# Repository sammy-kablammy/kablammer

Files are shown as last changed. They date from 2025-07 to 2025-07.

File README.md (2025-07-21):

# the kablammer

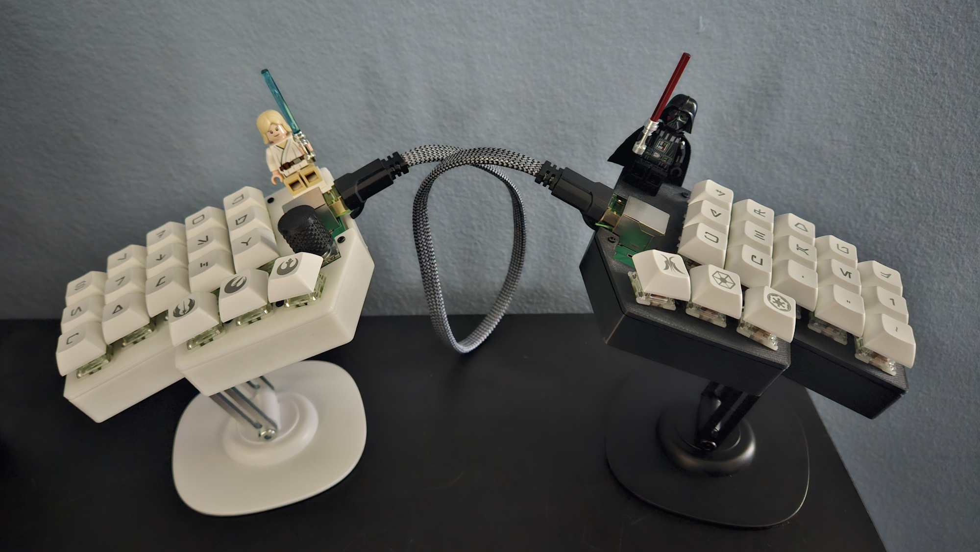
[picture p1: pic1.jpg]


A 36-key split ergo keeb to optimize your efficiency in dynamic heuristic analysis, improving synergy and interpolation of functional pseudo-discrete technical shizzle wizzles. Guaranteed to make you a 1000x front/back/middle end full stack vibe coded prompt engineer or your money back.

Features:
- [x] Reversible PCB
- [x] RP2040 zero microcontrollers (cheap + uses USB C)
- [x] Rotary encoder for volume or scrollwheel
- [x] RJ45 connects the two halves
- [x] Can seat two minifigures for moral support during intense debugging sessions

Case is made in FreeCAD. I just use the same model for both halves, but mirrored. The halves are not exactly the same, so you'll get slightly larger slots than necessary. I use a magsafe sticker on the bottom of each half. Then you can use magsafe phone stands for tenting.

Firmware is in [my QMK fork](https://github.com/sammy-kablammy/qmk_firmware.git).

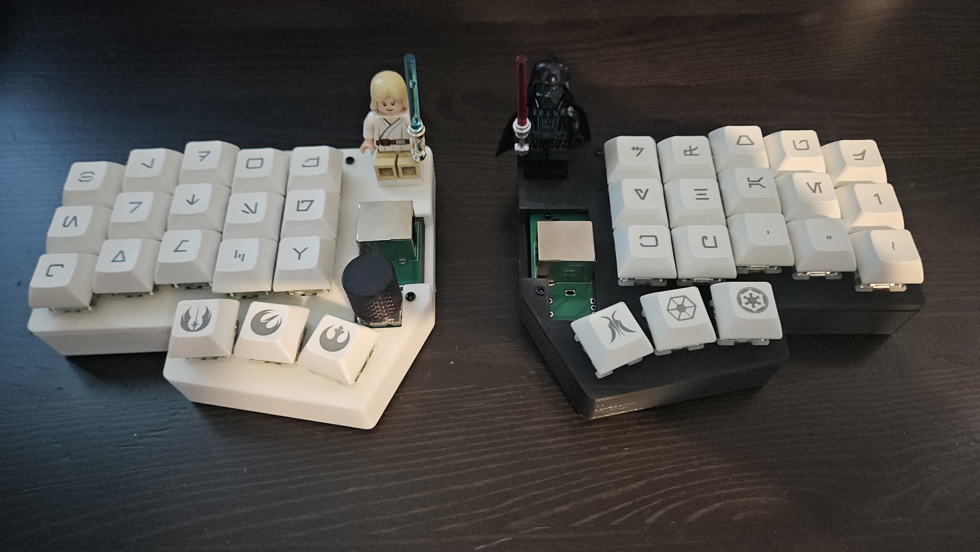
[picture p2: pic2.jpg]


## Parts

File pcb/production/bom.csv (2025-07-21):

Designator | Footprint | Quantity | Value | LCSC Part #
D1, D10, D11, D12, D13, D14, D15, D16, D17, D18, D19, D2, D3, D4, D5, D6, D7, D8, D9 | Diode_DO-35 | 19 | Diode
J1 | RJ45_Ninigi_GE | 1 | RJ45_Shielded_left
J2 | RJ45_Ninigi_GE | 1 | RJ45_Shielded_right
S1, S10, S11, S12, S13, S14, S15, S16, S17, S18, S2, S3, S4, S5, S6, S7, S8, S9 | Hotswap_MX_1.00u_reversible | 18 | Keyswitch
SW1 | Encoder_EC11_MX | 1 | RotaryEncoder_Switch
U2 | RP2040_Zero | 1 | RP2040_Zero

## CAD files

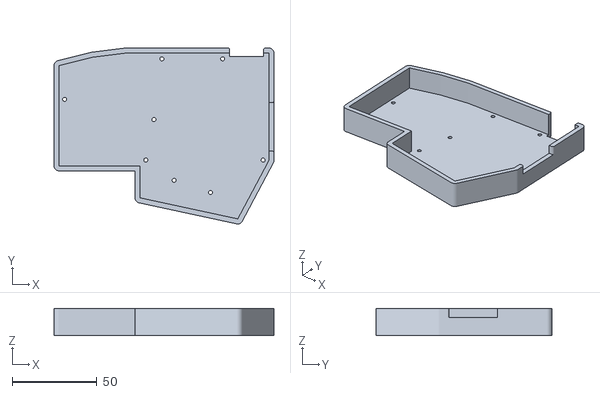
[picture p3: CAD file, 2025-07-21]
case/kablammer_case-LeftBottom.stl
129.4 x 103.5 x 16.0

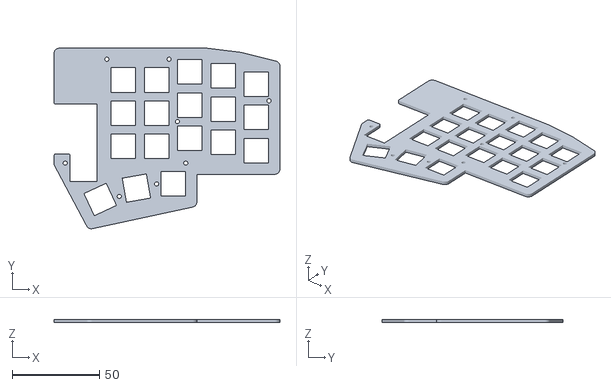
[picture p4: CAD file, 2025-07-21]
case/kablammer_case-RightTop.stl
129.5 x 103.5 x 2.00

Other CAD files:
case/kablammer_case-RightBottom.stl
case/kablammer_case-LeftTop.stl

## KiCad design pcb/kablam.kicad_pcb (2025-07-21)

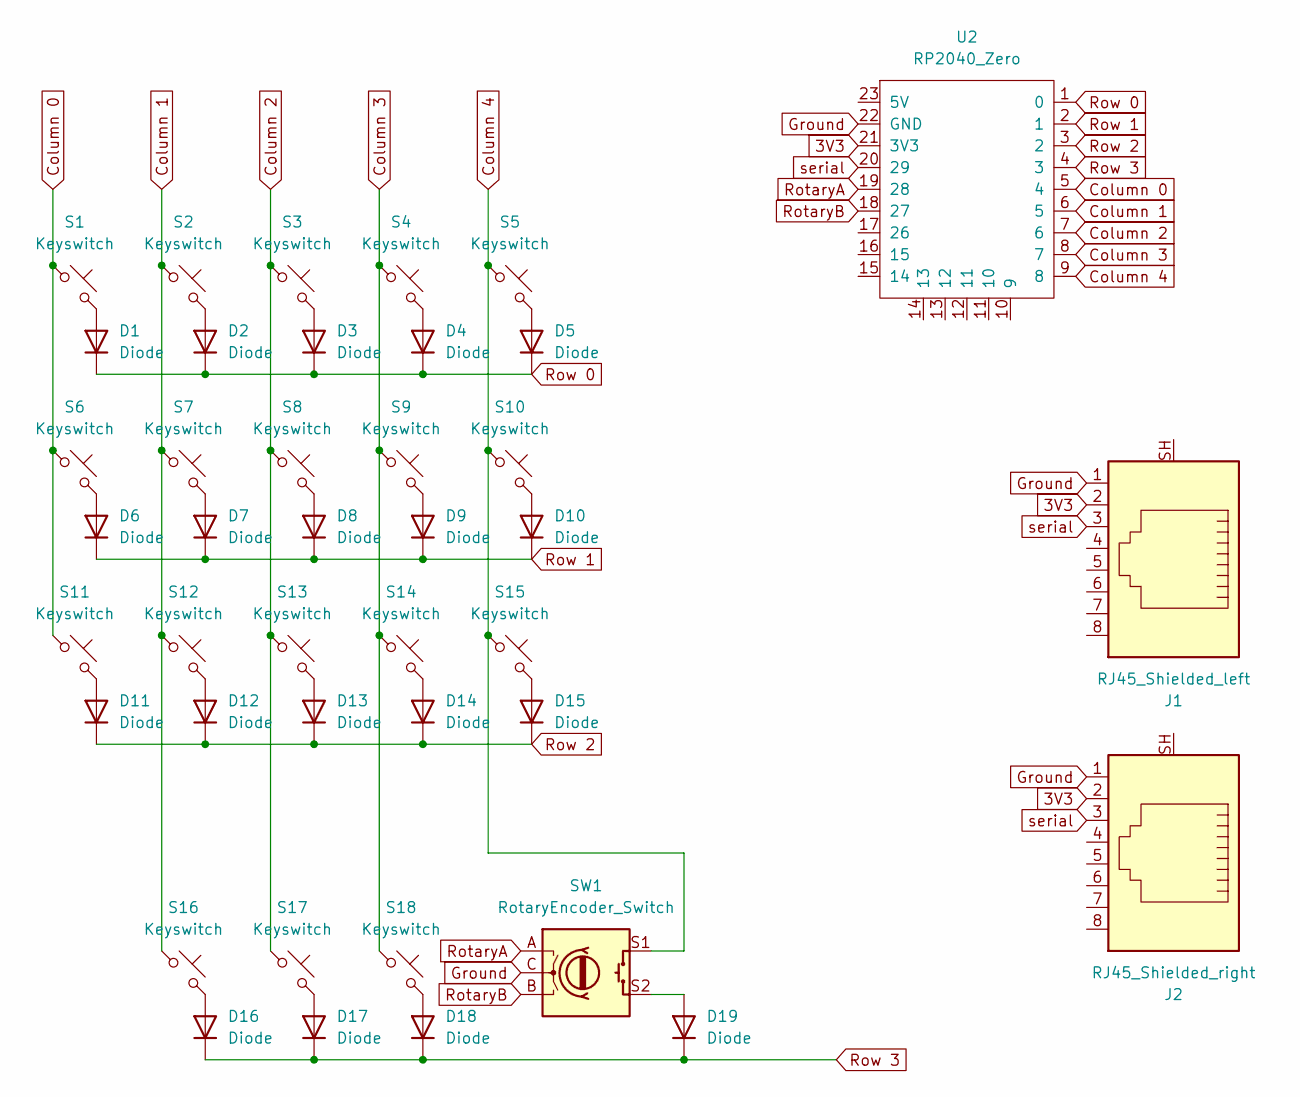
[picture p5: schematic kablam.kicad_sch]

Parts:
D1, D2, D3, D4, D5, D6, D7, D8, D9, D10, D11, D12, D13, D14, D15, D16, D17, D18, D19: Diode; Diode_DO-35
J1: RJ45_Shielded_left; RJ45_Ninigi_GE
J2: RJ45_Shielded_right; RJ45_Ninigi_GE
S1, S2, S3, S4, S5, S6, S7, S8, S9, S10, S11, S12, S13, S14, S15, S16, S17, S18: Keyswitch; Hotswap_MX_1.00u_reversible
SW1: RotaryEncoder_Switch; Encoder_EC11_MX
U2: RP2040_Zero

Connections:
3V3: J1.2, J2.2, U2.21 (3V3)
Column 0: S1.1, S6.1, S11.1, U2.5 (4)
Column 1: S2.1, S7.1, S12.1, S16.1, U2.6 (5)
Column 2: S3.1, S8.1, S13.1, S17.1, U2.7 (6)
Column 3: S4.1, S9.1, S14.1, S18.1, U2.8 (7)
Column 4: S5.1, S10.1, S15.1, SW1.S1, U2.9 (8)
Ground: J1.1, J2.1, SW1.C, U2.22 (GND)
unnamed: D1.2 (A), S1.2
unnamed: D2.2 (A), S2.2
unnamed: D3.2 (A), S3.2
unnamed: D4.2 (A), S4.2
unnamed: D5.2 (A), S5.2
unnamed: D6.2 (A), S6.2
unnamed: D7.2 (A), S7.2
unnamed: D8.2 (A), S8.2
unnamed: D9.2 (A), S9.2
unnamed: D10.2 (A), S10.2
unnamed: D11.2 (A), S11.2
unnamed: D12.2 (A), S12.2
unnamed: D13.2 (A), S13.2
unnamed: D14.2 (A), S14.2
unnamed: D15.2 (A), S15.2
unnamed: D16.2 (A), S16.2
unnamed: D17.2 (A), S17.2
unnamed: D18.2 (A), S18.2
unnamed: D19.2 (A), SW1.S2
RotaryA: SW1.A, U2.19 (28)
RotaryB: SW1.B, U2.18 (27)
Row 0: D1.1 (K), D2.1 (K), D3.1 (K), D4.1 (K), D5.1 (K), U2.1 (0)
Row 1: D6.1 (K), D7.1 (K), D8.1 (K), D9.1 (K), D10.1 (K), U2.2 (1)
Row 2: D11.1 (K), D12.1 (K), D13.1 (K), D14.1 (K), D15.1 (K), U2.3 (2)
Row 3: D16.1 (K), D17.1 (K), D18.1 (K), D19.1 (K), U2.4 (3)
serial: J1.3, J2.3, U2.20 (29)

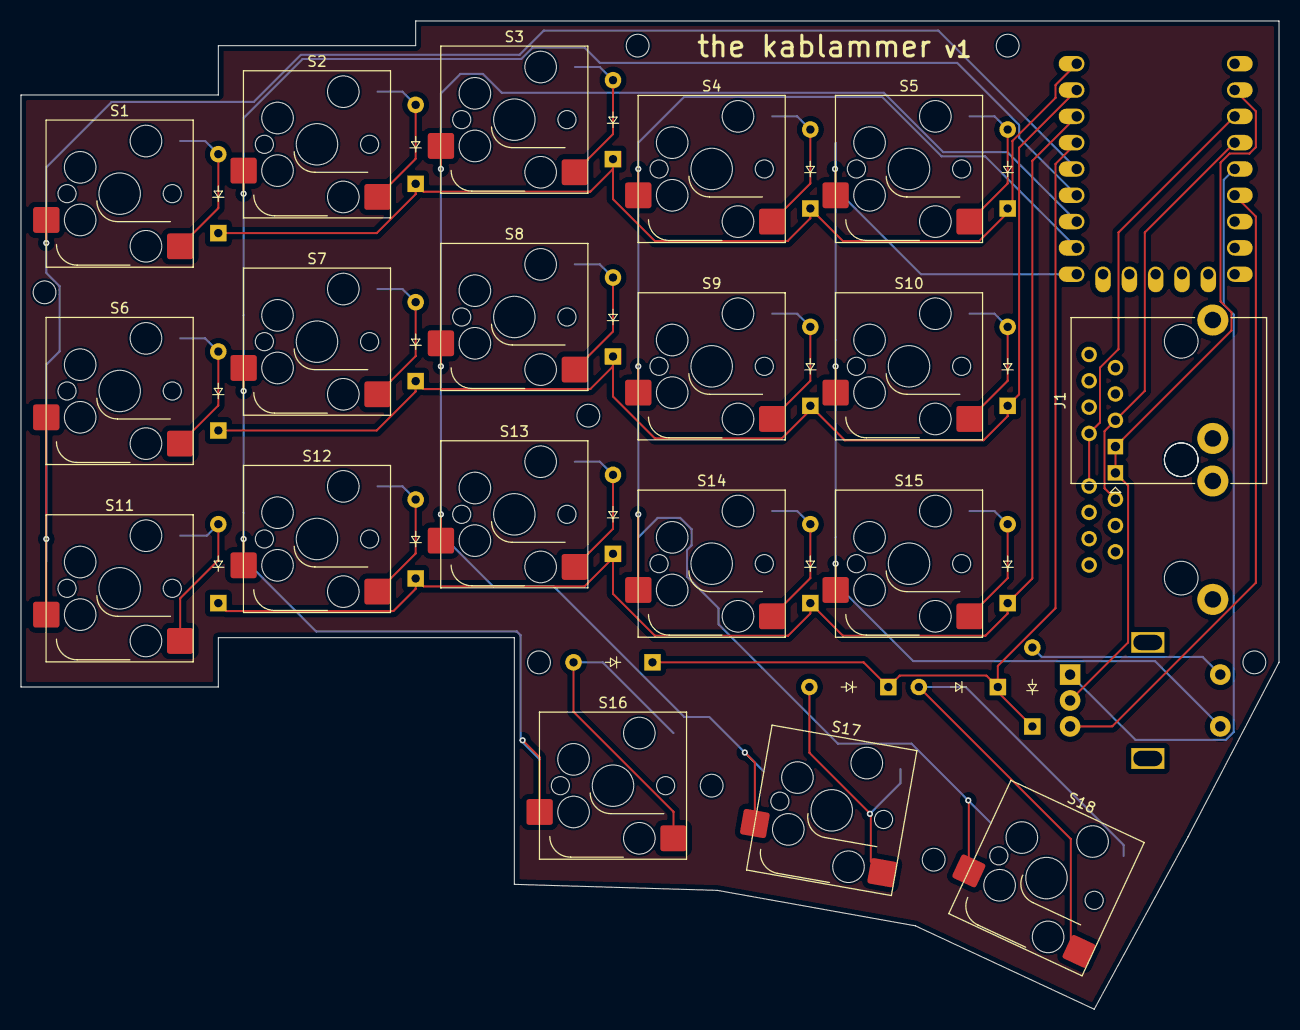
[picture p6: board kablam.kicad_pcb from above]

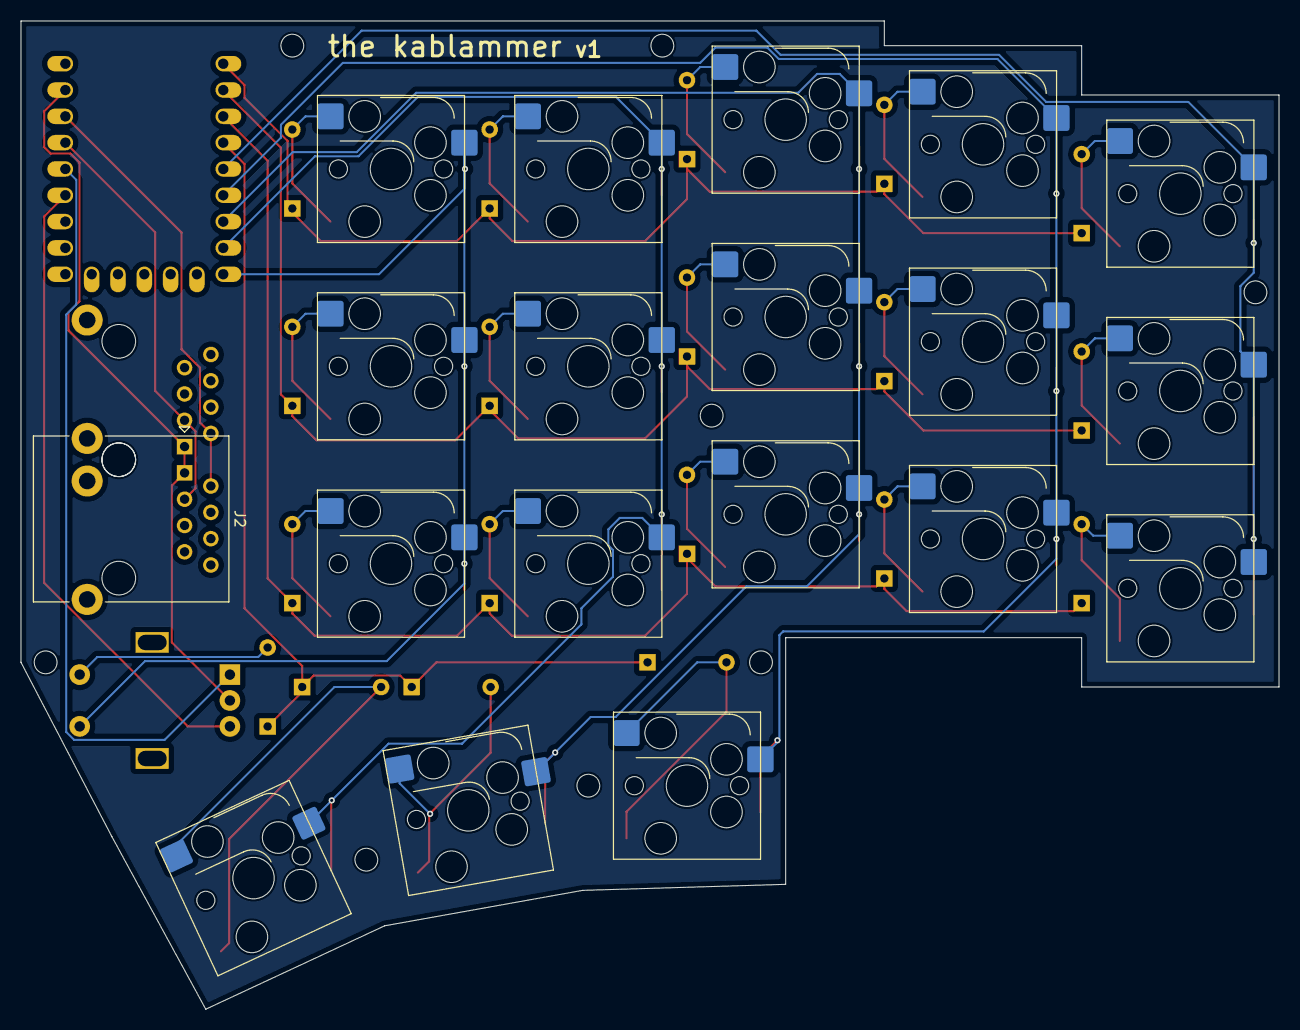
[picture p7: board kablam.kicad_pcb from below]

Board: 2 copper layers, 121.4 x 95.4 mm, 41 parts (2 on the bottom side), 33 nets.
